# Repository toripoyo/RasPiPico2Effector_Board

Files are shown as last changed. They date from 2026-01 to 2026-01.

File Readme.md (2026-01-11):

Raspberry Pi Pico2 でつくる簡単エフェクターです。  
KiCadプロジェクトは本リポジトリ、Raspberry Pi Pico2 のソフトウェアは [RasPiPico2Effector_Software](https://github.com/toripoyo/RasPiPico2Effector_Software) を参照してください。

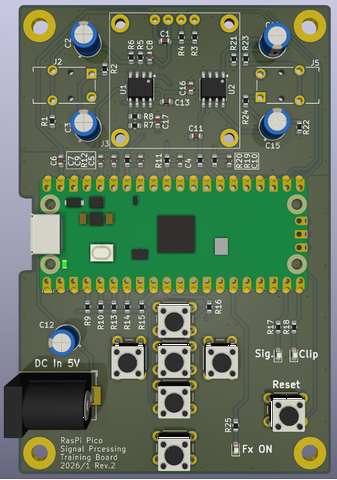
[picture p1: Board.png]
Kicad Data

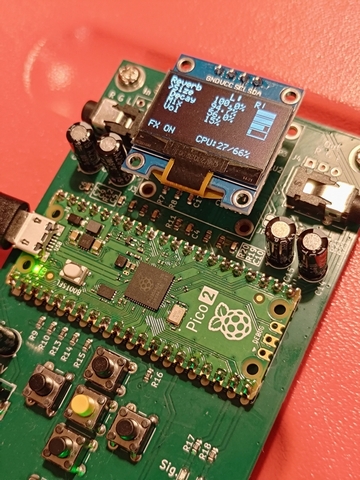
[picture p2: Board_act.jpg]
Actual Board


## スペック

| パラメータ | 値 |
|---|---|
| MCU | RP2350 (Cortex-M33) @ 250 MHz |
| サンプリングレート | 約44.1 kHz|
| オーバーサンプリング | 4倍 |
| 信号処理ブロックサイズ | 16サンプル |
| ADC分解能 | 12ビット |
| PWM分解能 | 11ビット |
| PWM周波数 | 約122 kHz (250 MHz / PWM分解能) |
| Core 0 | ADC入力/DMA、PWM出力、UI/ディスプレイ |
| Core 1 | オーディオエフェクト処理 |

※ in/out のアナログLPFはfc=15kHzです。

## 操作方法
- On/Thru: エフェクトOn/Off
- Enter: エフェクト種類の切り替え
- Up/Down: 操作パラメータ選択
- Left/Right: パラメータ変更

## 書き込み方法
Reset ボタンを押しながら、RasPi Pico上のBOOTSELボタンを押し、PCからストレージとして認識される状態にしてください。

## ライセンス
[LICENSE](./LICENSE)

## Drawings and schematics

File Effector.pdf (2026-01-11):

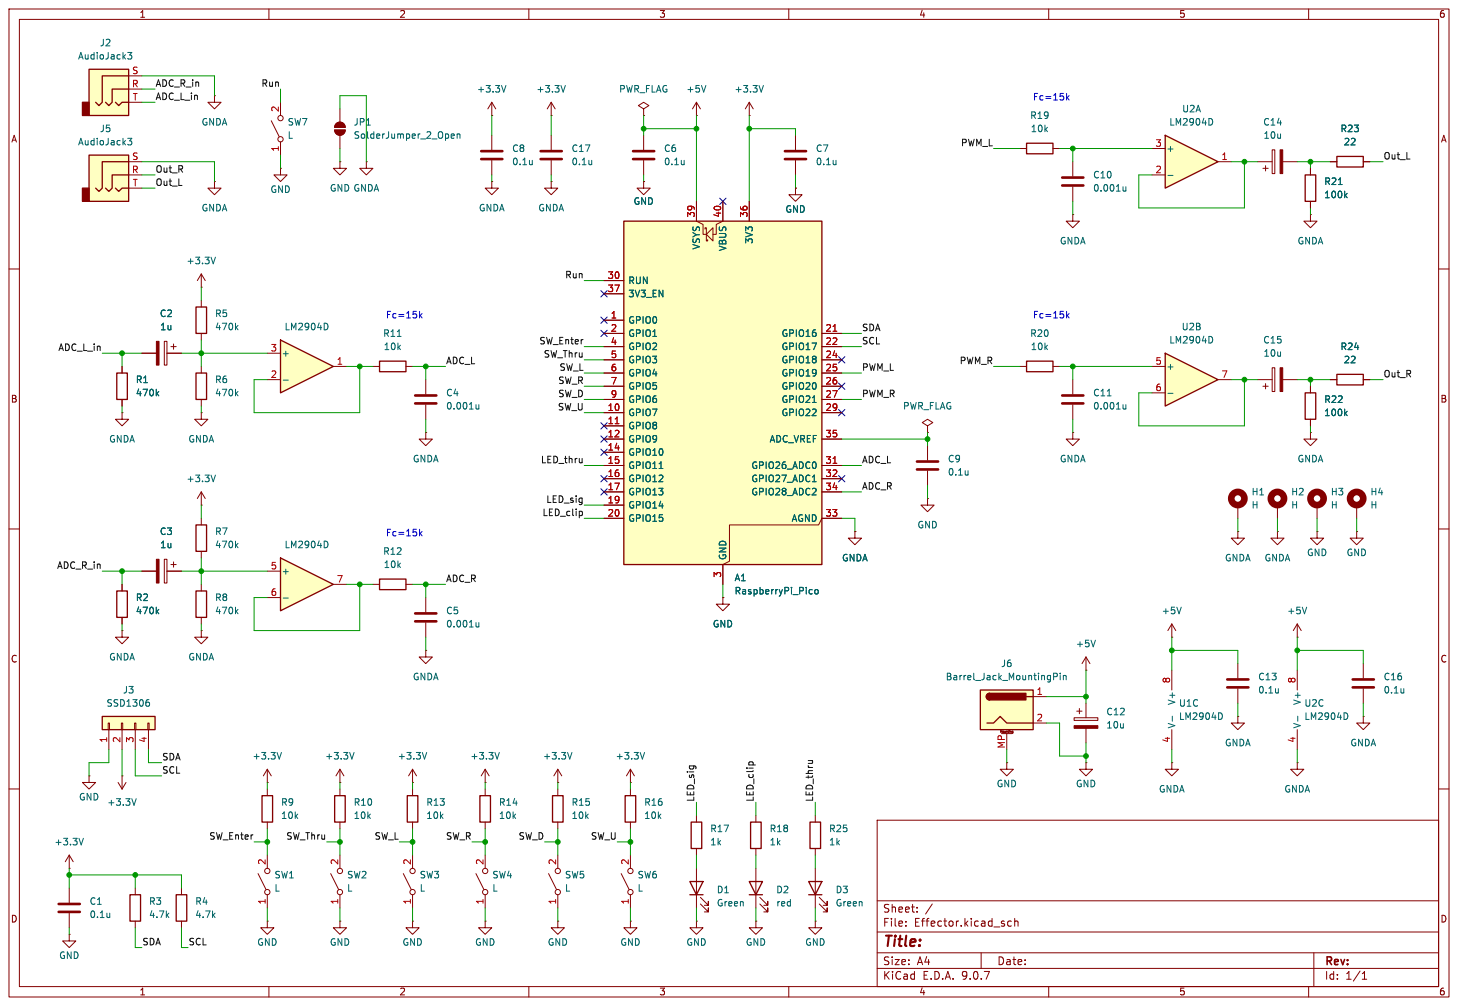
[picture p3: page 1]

3 3V3 36 GPIO16 21 GPIO17 22 GPIO18 24 GPIO19 25 GPIO20 26 GPIO21 27 GPIO22 29 ADC_VREF 35 GPIO26_ADC0 31 GPIO27_ADC1 32 GPIO28_ADC2 34 AGND 33 GND GNDA GND GND

Id: 1/1 Title: File: Effector.kicad_sch Sheet: / GND

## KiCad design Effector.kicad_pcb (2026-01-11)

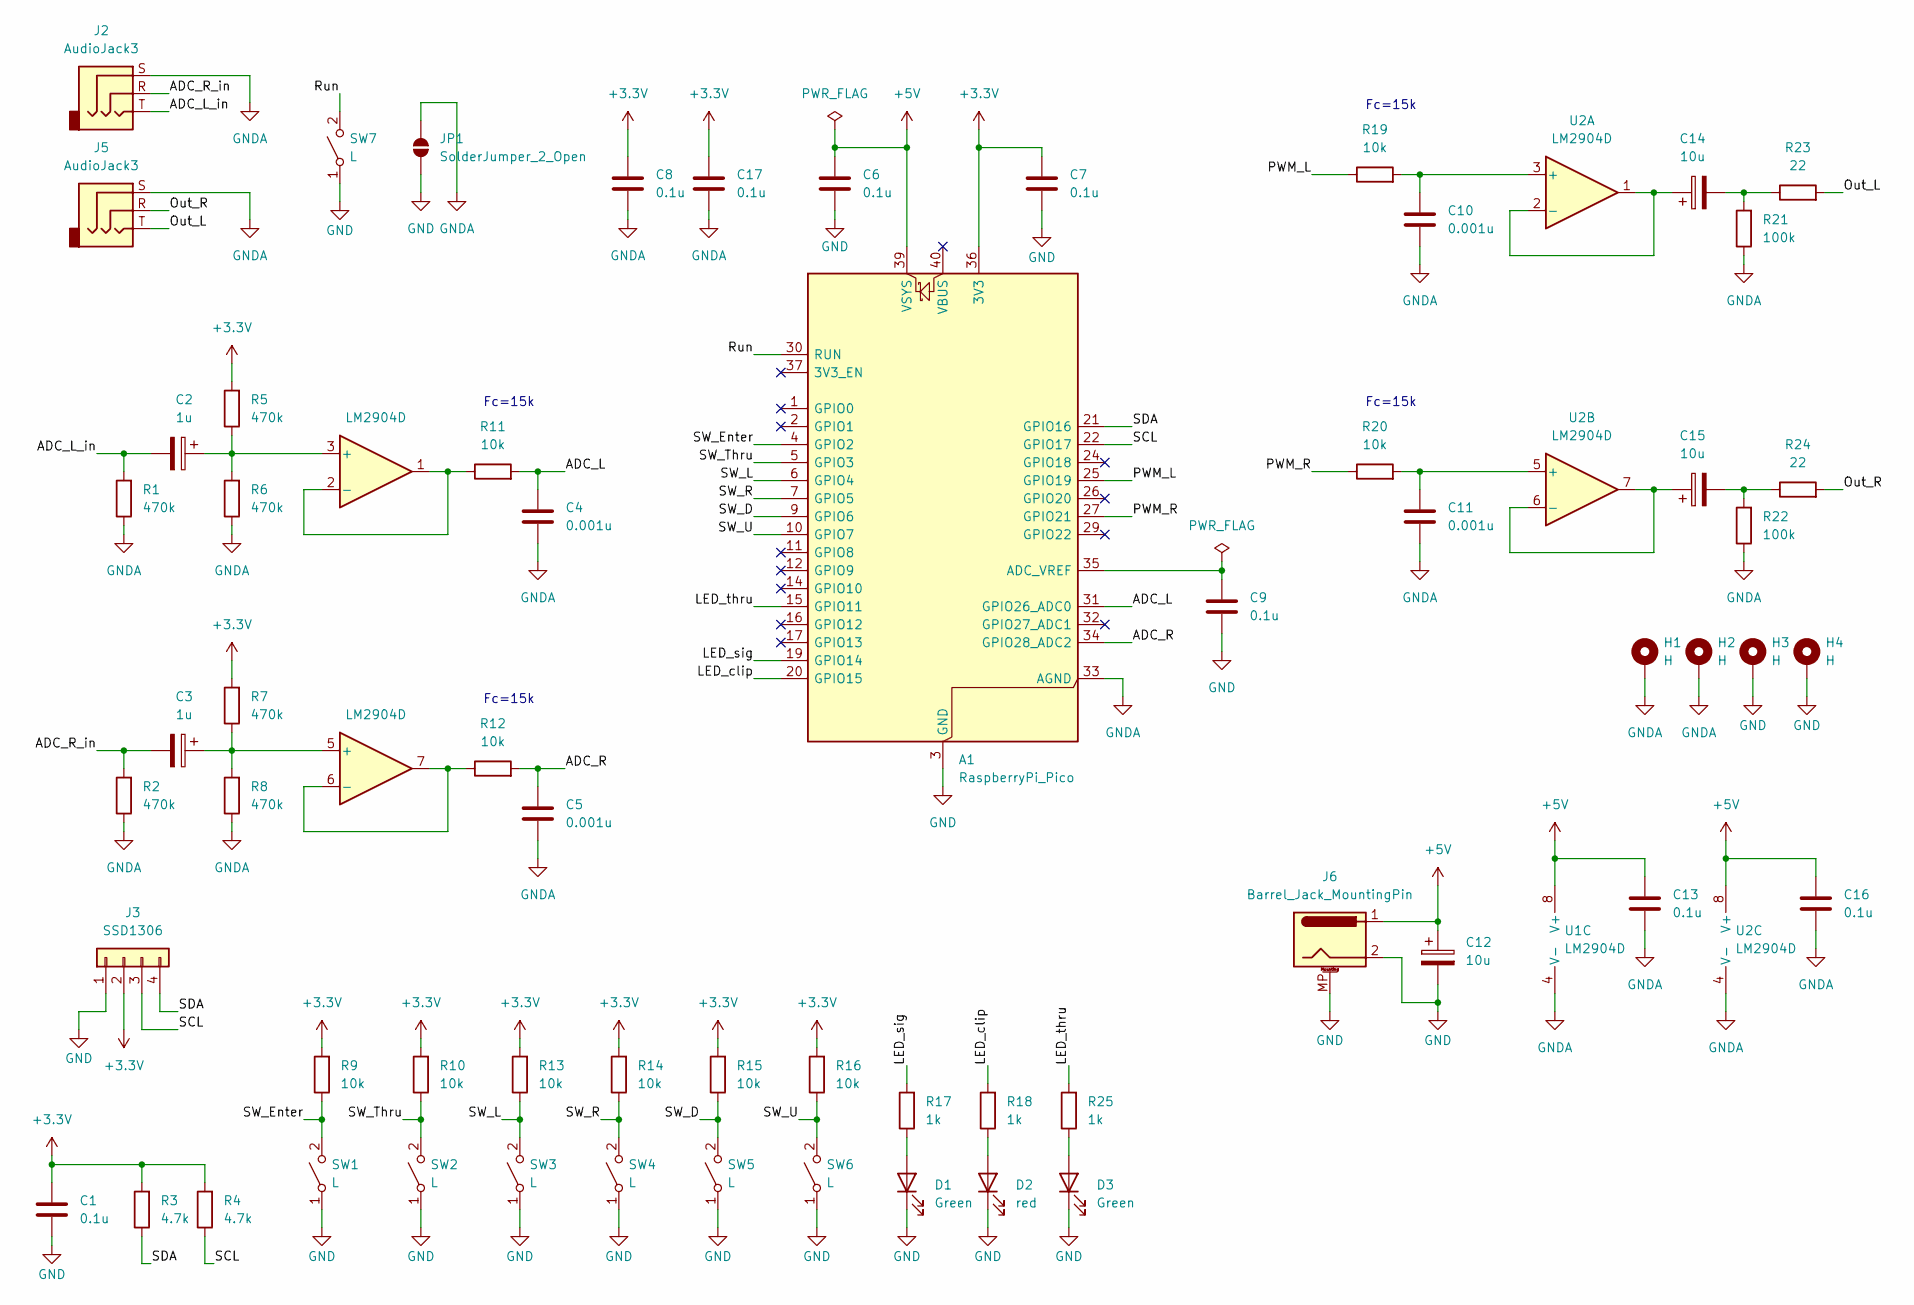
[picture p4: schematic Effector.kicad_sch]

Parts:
A1: RaspberryPi_Pico; RaspberryPi_Pico_Common_Unspecified
C1, C6, C7, C8, C9, C13, C16, C17: 0.1u; C_0603_1608Metric
C2, C3: 1u; CP_Radial_D5.0mm_P2.00mm
C4, C5, C10, C11: 0.001u; C_0603_1608Metric
C12, C14, C15: 10u; CP_Radial_D5.0mm_P2.00mm
D1, D3: Green; LED_0603_1608Metric
D2: red; LED_0603_1608Metric
H1, H2, H3, H4: H; MountingHole_3.2mm_M3_Pad
J2, J5: AudioJack3; Jack_3.5mm_Switronic_ST-005-G_horizontal
J3: SSD1306
J6: Barrel_Jack_MountingPin; BarrelJack_Horizontal
JP1: SolderJumper_2_Open; SolderJumper-2_P1.3mm_Open_RoundedPad1.0x1.5mm
R1, R2, R5, R6, R7, R8: 470k; R_0603_1608Metric
R3, R4: 4.7k; R_0603_1608Metric
R9, R10, R11, R12, R13, R14, R15, R16, R19, R20: 10k; R_0603_1608Metric
R17, R18, R25: 1k; R_0603_1608Metric
R21, R22: 100k; R_0603_1608Metric
R23, R24: 22; R_0603_1608Metric
SW1, SW2, SW3, SW4, SW5, SW6, SW7: L; SW_PUSH_6mm_H4.3mm
U1, U2: LM2904D; SOIC-8_3.9x4.9mm_P1.27mm

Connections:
+3.3V: A1.36 (3V3), C1.1, C7.1, C8.1, C17.1, J3.2, R3.2, R4.2, R5.2, R7.2, R9.2, R10.2, R13.2, R14.2, R15.2, R16.2
+5V: A1.39 (VSYS), C6.1, C12.1, C13.1, C16.1, J6.1, U1.8 (V+), U2.8 (V+)
/ADC_L: A1.31 (GPIO26_ADC0), C4.1, R11.2
/ADC_L_in: C2.2, J2.T, R1.2
/ADC_R: A1.34 (GPIO28_ADC2), C5.1, R12.2
/ADC_R_in: C3.2, J2.R, R2.2
/LED_clip: A1.20 (GPIO15), R18.2
/LED_sig: A1.19 (GPIO14), R17.2
/LED_thru: A1.15 (GPIO11), R25.2
/Out_L: J5.T, R23.2
/Out_R: J5.R, R24.2
/PWM_L: A1.25 (GPIO19), R19.1
/PWM_R: A1.27 (GPIO21), R20.1
/Run: A1.30 (RUN), SW7.2 (B)
/SCL: A1.22 (GPIO17), J3.3, R4.1
/SDA: A1.21 (GPIO16), J3.4, R3.1
/SW_D: A1.9 (GPIO6), R15.1, SW5.2 (B)
/SW_Enter: A1.4 (GPIO2), R9.1, SW1.2 (B)
/SW_L: A1.6 (GPIO4), R13.1, SW3.2 (B)
/SW_R: A1.7 (GPIO5), R14.1, SW4.2 (B)
/SW_Thru: A1.5 (GPIO3), R10.1, SW2.2 (B)
/SW_U: A1.10 (GPIO7), R16.1, SW6.2 (B)
GND: A1.3 (GND), A1.8 (GND), A1.13 (GND), A1.18 (GND), A1.23 (GND), A1.28 (GND), A1.38 (GND), C1.2, C6.2, C7.2, C9.2, C12.2, D1.1 (K), D2.1 (K), D3.1 (K), H3.1, H4.1, J3.1, J6.2, J6.MP (MountPin), JP1.1 (A), SW1.1 (A), SW2.1 (A), SW3.1 (A), SW4.1 (A), SW5.1 (A), SW6.1 (A), SW7.1 (A)
GNDA: A1.33 (AGND), C4.2, C5.2, C8.2, C10.2, C11.2, C13.2, C16.2, C17.2, H1.1, H2.1, J2.S, J5.S, JP1.2 (B), R1.1, R2.1, R6.1, R8.1, R21.1, R22.1, U1.4 (V-), U2.4 (V-)
unnamed: A1.35 (ADC_VREF), C9.1
unnamed: C14.2, R21.2, R23.1
unnamed: C15.2, R22.2, R24.1
unnamed: D1.2 (A), R17.1
unnamed: D2.2 (A), R18.1
unnamed: D3.2 (A), R25.1
unnamed: C2.1, R5.1, R6.2, U1.3 (+)
unnamed: R11.1, U1.1, U1.2 (-)
unnamed: C3.1, R7.1, R8.2, U1.5 (+)
unnamed: R12.1, U1.6 (-), U1.7
unnamed: C10.1, R19.2, U2.3 (+)
unnamed: C14.1, U2.1, U2.2 (-)
unnamed: C11.1, R20.2, U2.5 (+)
unnamed: C15.1, U2.6 (-), U2.7

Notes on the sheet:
Fc=15k

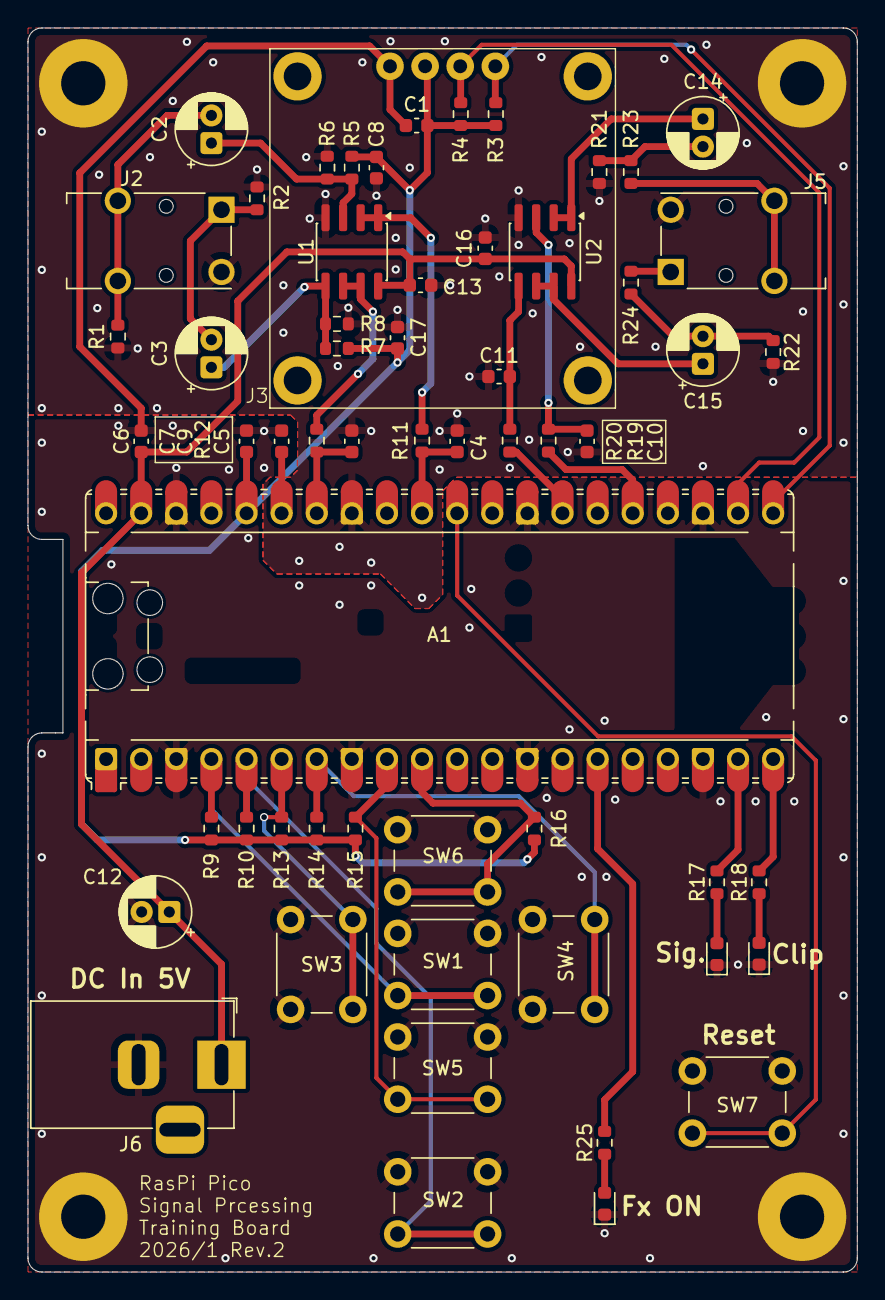
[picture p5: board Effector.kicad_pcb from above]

Board: 2 copper layers, 60.0 x 90.0 mm, 64 parts (1 on the bottom side), 38 nets.

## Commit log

2026-01-11 Add Circuit
    [Effector.kicad_pcb, Effector.kicad_sch]
2026-01-11 ドキュメントを追加
